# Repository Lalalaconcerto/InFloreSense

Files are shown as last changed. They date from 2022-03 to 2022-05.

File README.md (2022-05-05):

# InfloreSense

This project is to visualise and sonify moisture and temperature plant data using a leaf as the user interface: A leaf is used as a touch sensor to trigger the data to be revealed to a user. The plant’s needs were expressed visually with an 8x8 pixel matrix and auditorily with a choral voice and bass drum. We sonified the full temperature and moisture range that could be expected, allowing our users to develop an intuition for the plant’s exact conditions from listening to the audio.

## Videos

Introduction

https://youtu.be/Un4EG1IXvOg

How does it work?

https://youtu.be/Bgrby5ReTXs

## Hardware needed

- Raspberry pi
- Arduino Uno wifi 
- DHT-22 sensor(Input)
- Soil moisture sensor(Input)
- Capacitive touch sensor(Input)
- 8*8 matric LED (Output)
- Speaker(Output)

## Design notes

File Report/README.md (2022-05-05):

# InFloreSense: Visualised and Sonified Plant Data

[GitHub Repo](https://github.com/Lalalaconcerto/InFloreSense)

## Problem

Plants can be difficult to take care of. Shortly after purchase, plants frequently die due to overwatering (Vanzile 2021). Plants also often die due to underwatering after the novelty of the new plant wears off, with Art Markman of the University of Texas attributing this issue to a lack of reminders (Bregel 2019). More experienced plant-owners, such as florist Liz Vayda, recommend that the best way to become a better plant caretaker is to simply learn more about the plants and pay attention to them (Bregel 2019).

While existing plant monitors will give information about the current needs of a plant, the data they provide is either overly simplified or difficult to interpret. Additionally the data is only accessible via a visual interface. By providing data that is overly simplified, these plant monitors do not allow plant owners to develop their own intuitive sense of their plants’ needs. Providing data that is difficult to interpret can prevent the data from being acted on, potentially causing the plant owner to ignore the data completely. Lastly, the visual-only interfaces make plant monitors inaccessible to blind or hard-of-sight plant-owners.

## Motivation

Infloresense helps less experienced plant-owners keep their plants alive without stifling the learning process in which they develop an intuition for how to take care of their plants. Our device combines visual indicators of the general conditions of the plant with a sound-based mapping that expresses the conditions of the plant in more detail. By combining the visual dashboard with sonification, Infloresense will stoke curiosity in all plant-owners as they discover how the sound changes due to subtle changes in the plants’ conditions and understand what sounds indicate a healthy plant. Additionally, it makes our device accessible for blind plant-owners, who can rely solely on the sonification in understanding the plant's conditions.

## Inspiration

Having previous experience developing a standard plant monitor, our project was chiefly inspired by sonification works. Mogees is a discontinued device that would adhere to any surface, including that of trees, and by connecting to an iPhone, it would map any vibrations on that surface to a custom instrument chosen by the user. We were inspired by the way this project allowed for co-creation of music between a user and the natural environment. Ototo, a microcontroller-based device that connected to everyday objects as keys and modulators of a synthesiser, inspired us in its approach of being self-contained and not requiring a mobile phone to function. Lastly, we were inspired by the work of Mileece. Mileece attaches electrodes to plant leaves, turning voltage differences between the leaves into ambient music. We were inspired by her approach of connecting the leaves of the plant to her electronic instrument.

## Documentation of Prototyping Process

### Initial Design

We initially planned to visualise and sonify the voltage signals produced by a plant. This required significant voltage amplification, but was able to recognise water input or rustling of leaves when developed as a standalone circuit. However, the data was too noisy to capture these stimuli when other modules were attached to the Arduino. Thus, this option was not selected for this project.

### Second Design

#### User Interface

Instead of measuring intra-plant voltage, we pivoted to visualising and sonifying moisture and temperature plant data using a leaf as the user interface: we used a leaf as a touch sensor to trigger the data to be revealed to a user. The plant’s needs were expressed visually with an 8x8 pixel matrix and auditorily with a choral voice and bass drum. We sonified the full temperature and moisture range that could be expected, allowing our users to develop an intuition for the plant’s exact conditions from listening to the audio. The flow chart of the project is shown below.

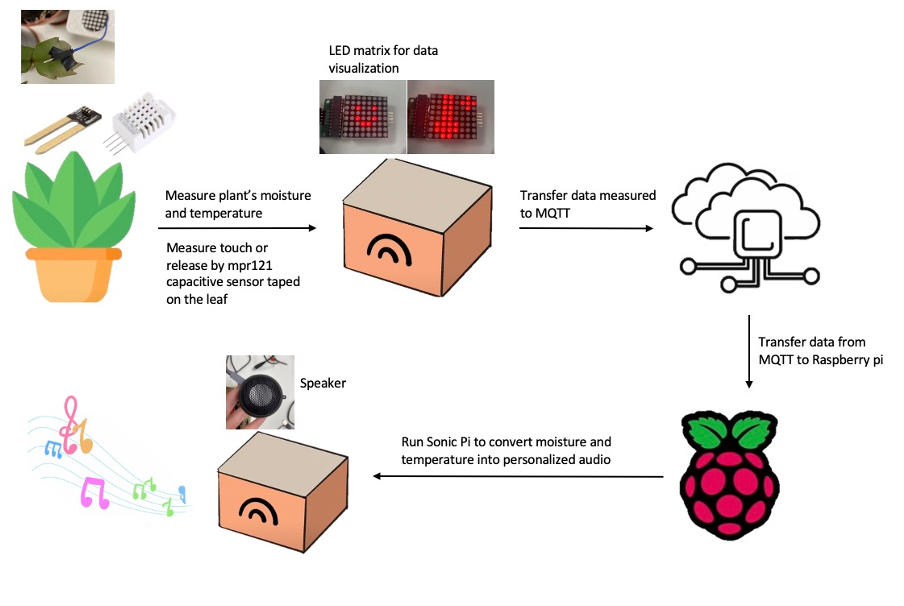
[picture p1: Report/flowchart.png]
Flow chart flow chart

  
#### Moisture sensing

Capacitive soil moisture sensor can measure the soil moisture distrectly. The main component of the sensor is the humidity sensitive capacitor and the number of absorbed water changes with the change in ambient humidity(Boudaden,et,al,2018). By measuring the capacitance value, it can be converted into a humidity value. The soil moisture value can be directly read using the digital pin of the Arduino.

#### Temperature Sensing

DHT-22 can measure ambient temperature. The principle of DHT22 measuring temperature and humidity is to measure the surrounding air through the built-in capacitive humidity sensor and thermistor(Kim,et al, 2021). After obtaining the temperature and humidity values, a digital signal is sent to the main control board from the Data pin.

#### Touch Sensing

MPR 121 capacitive touch sensor can handle up to 12 individual touch pads. Each pin can be connected to wires and be taped to leaves as a touch switch(Ada,et al,2022). We programmed it with the Arduino MPR121 library so that touch will set LED matrix and speaker on, and release will set LED matrix and speaker off.

#### Visualisation

The LED matrix consists of 64 red LEDs. Some simple images were displayed with five different icons to show different conditions of the plant. These icons are shown below; from left to right, they correspond to healthy conditions, high temperature, low temperature, overly moist soil, and overly dry soil. Every time you touch a leaf, the icon will show the current conditions until 5 seconds after your finger has been removed. If neither humidity nor temperature are in the correct range, humidity and temperature icons will be alternately displayed on the LED matrix for one second. If one metric is in a good range, then the matrix will exclusively show the icon representing the metric that needs to be changed. If both conditions are good, the smiling icon will be shown.

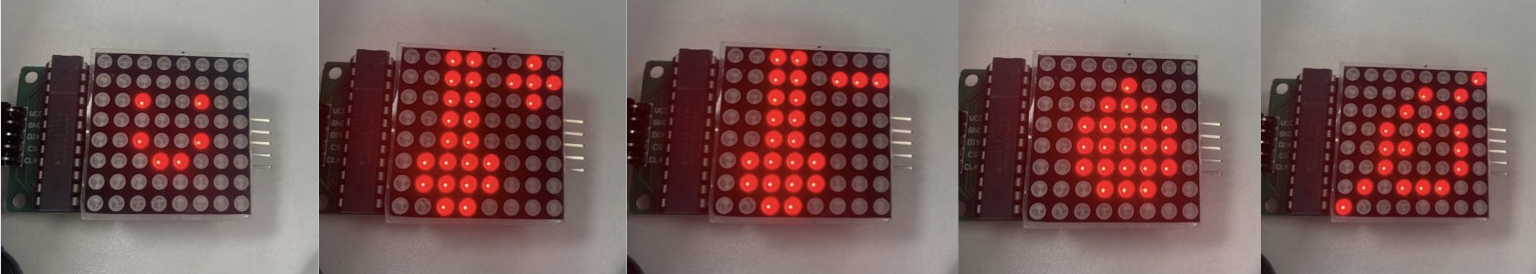
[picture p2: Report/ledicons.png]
LED icons


#### Data flow to Raspberry Pi

Moisture data, temperature data, and touch data are sent once per second to an MQTT server in a channel labelled "Infloresense". A continuously-running Python script on the Raspberry Pi monitors the MQTT data feed from the “Infloresense” channel, and stores the values in a plain text file, resetting the plain text file every second. Simultaneously, a shell script repeatedly runs runs a Sonic Pi script via a Python-based command line interface, using the plain text file as an input parameter.

#### Sonification

Sonic Pi plays two sound samples synchronously, a choral voice and a bass drum. These two samples are sped up according to the amount of moisture in the soil and temperature of the surrounding environment, respectively. Different continuous functions are used to ensure that the full range of realistic moistures and temperatures is sonified in a distinguishable and musical manner. We have specifically tied higher moisture and temperature levels to more sped up versions of the two instruments.

#### Enclosure

Before designing the enclosure, we measured the dimensions of each part individually to create a compact enclosure. However, we found that with wire connections, a larger enclosure was needed. See below for a final rendering of our enclosure.

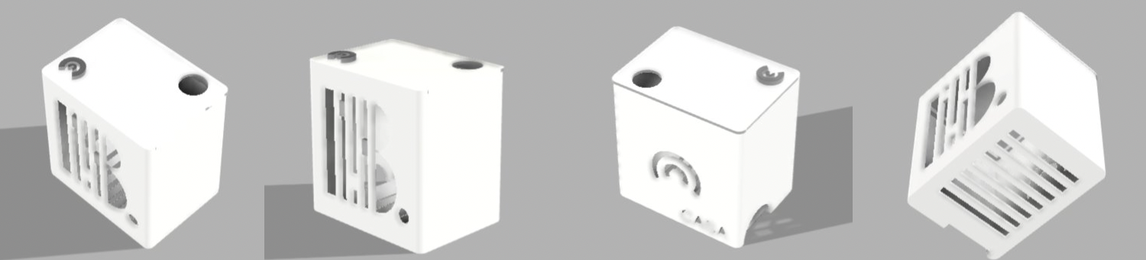
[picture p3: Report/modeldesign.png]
Model design


##### Model design

We used Fusion360 to design the enclosure. For future prototypes, we expect simulating the placement of all of the components inside the enclosure will help us to design the most spatially-efficient enclosure.

##### Wires outlet

Multiple wires need to come out of the enclosure to connect to external devices, including the charging cable for Arduino, the charging cable for a Raspberry Pi, the cable connecting the touch sensor and the cable connecting the soil moisture sensor. For this, we designed some gaps to let these wires come out of the enclosure. These gaps are designed to emulate the appearance of a sound mixer.

##### Heat dissipation

When placed in the first prototype enclosure, the Arduino and Raspberry Pi microcontrollers were found to be hot which distorted the readings of the DHT-22 sensor. To solve this problem, we added a strip-shaped gap at the bottom of the box to dissipate heat.

## Critical Reflection and Future Improvements

### All-in-one design

Currently, our device is separate from the plant, with wires exposed on the outside of the enclosure. In the future, we will design an enclosure to put all the components inside, including the plant.

### Power supply

The Raspberry Pi and Arduino board are currently powered by different external power supplies. In the future, we will place a small power strip in the enclosure to connect the two boards with an external power supply in a more consolidated manner.

### Audio hardware design

We put the speaker and other components directly into the enclosure, but this leads to poor speaker sound. If amplification could be incorporated into the outside of the enclosure, it would improve the musical quality. We are interested in testing out a thin-film loudspeaker adhered to the surface of the enclosure, as recently developed by researchers at MIT (Han, Lang, and Bulovic 2022).

### Leaf touch interface

The touch sensor is wired in a way that does not hide the wire and usually requires the user to pinch it in order to turn on InfloreSense's visualisations. To make the user interaction feel more organic, we would like to explore using an electrode pad to detect a touch to any portion of a leaf.

### More channels

Right now we only use one touch sensor. If more than one channel to connect to different leaves is used, more interesting music could be produced, based on either other parameters relating to the care of the plant, or even combining the plant's data with external sustainability or environmental data (such as the user's electricity usage, the air pollution forecast in one's neighbourhood that day, or the chance of rain).

### Accessibility

To make our device more accessible to hard-of-sight individuals, it would be worth adding an "audio-only" mode, potentially by using a wake-word to get InfloreSense to say its needs before playing the sonification until it is told to stop.

## References

Boudaden, J. _et al._ (2018) ‘Polyimide-Based Capacitive Humidity Sensor’, _Sensors_, 18(5), p. 1516. doi:10.3390/s18051516.

Bregel, S. (2019) ‘Perspective | Why I can’t take care of a plant’, _Washington Post_, 5 July. Available at: https://www.washingtonpost.com/outlook/why-i-cant-take-care-of-a-plant/2019/07/05/ee961b54-9788-11e9-8d0a-5edd7e2025b1_story.html (Accessed: 3 May 2022).

Dentaku (2014) _Ototo: Make Music from Anything_, _Kickstarter_. Available at: https://www.kickstarter.com/projects/905018498/ototo-make-music-from-anything (Accessed: 3 May 2022).

Fried, L. (2014) ‘Adafruit MPR121 12-Key Capacitive Touch Sensor Breakout Tutorial’, _Adafruit Learning System_, 25 July. Available at: https://learn.adafruit.com/adafruit-mpr121-12-key-capacitive-touch-sensor-breakout-tutorial/wiring (Accessed: 5 May 2022).

Han, J., Lang, J.H. and Bulović, V. (2022) ‘A Thin-Film Piezoelectric Speaker Based On An Active Microstructure Array’, in 2022 IEEE 35th International Conference on Micro Electro Mechanical Systems Conference (MEMS). 2022 IEEE 35th International Conference on Micro Electro Mechanical Systems Conference (MEMS), pp. 852–855. doi:10.1109/MEMS51670.2022.9699609.

Hermann, T., Hunt, A. and Neuhoff, J.G. (2011) ‘The Sonification Handbook’, p. 586.

Kim, J. _et al._ (2021) ‘Capacitive Humidity Sensor Based on Carbon Black/Polyimide Composites’, _Sensors_, 21(6), p. 1974. doi:10.3390/s21061974.

Mogees (2015) _Mogees - Play the World_. Available at: https://www.youtube.com/watch?v=G_hBhORGE6Y (Accessed: 26 April 2022).

Mogees (2016) _Mogees - Transform anything into a musical instrument._, _Kickstarter_. Available at: https://www.kickstarter.com/projects/mogeesplay/mogees (Accessed: 3 May 2022).

Motherboard (2014) _Meet the Sonic Artist Making Music with Plants: Sound Builders_. Available at: https://www.youtube.com/watch?v=wYU18eiiFt4 (Accessed: 3 May 2022).

Palmai, K. (2022) ‘How smart sensors can help us care for our houseplants’, _BBC News_, 21 February. Available at: https://www.bbc.com/news/business-60387006 (Accessed: 3 May 2022).

Vanzile, J. (2021) ‘Learn How to Not Kill Your Houseplants With Too Much Water’, _The Spruce_, 19 December. Available at: https://www.thespruce.com/tips-for-watering-houseplants-1902807 (Accessed: 3 May 2022).

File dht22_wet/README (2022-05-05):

This file is the skech for obtaining data for dht22 sensor and moisture sensor in Arduino.

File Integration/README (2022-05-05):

This is the Arduino final integration sketch.

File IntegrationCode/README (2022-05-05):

This is the integraton code for all input and output sensors in Arduino.(LED, touch sensor, dht22, and moisture sensor)

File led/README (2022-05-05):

This file is the design of the five different images according to different status of the plant with 8*8 LED matirx.

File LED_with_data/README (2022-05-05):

This file is the combination of the 8*8 LED Matrix skech and dht22 and moisture skech.

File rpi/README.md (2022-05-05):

# These files include all of the custom code needed to produce sonification of the plant's data
## Dependencies (to be installed on Raspberry Pi)
1. [Sonic Pi](https://sonic-pi.net)
2. [Sonic Pi Tool (Python)](https://github.com/emlyn/sonic-pi-tool)

## Steps to run:
1. Download all of these files to the Desktop of your Raspberry Pi
2. Open Sonic Pi
3. Run the `mqttToText.py` script in the `Thonny` Python IDE. Keep it running continuously.
4. Open a new terminal and run `watch -n 1 repeatedCheck.sh`

## Brief description of each script
- `infloresense.rb`: Sonification script, ran in Sonic Pi 
- `mqttToText.py`: updates `test.txt` with MQTT data
- `repeatedCheck.sh`: runs the Sonic Pi script every second
- `sonic-pi-tool.py`: copy of Sonic Pi Tool (mentioned above)
- `test.txt`: stores the most recent MQTT data

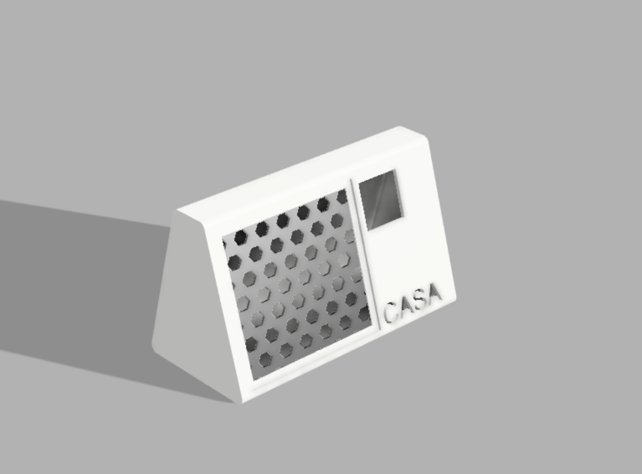
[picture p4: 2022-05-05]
Enclosure/Rendering image.png

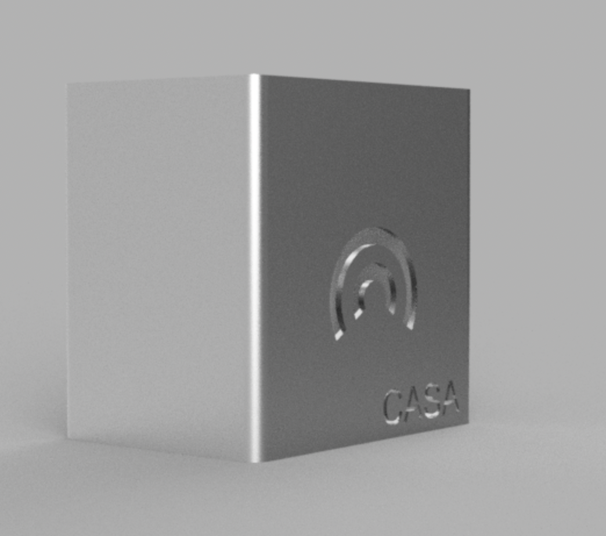
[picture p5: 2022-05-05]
Enclosure/Screenshot 2022-04-12 at 14.10.03.png

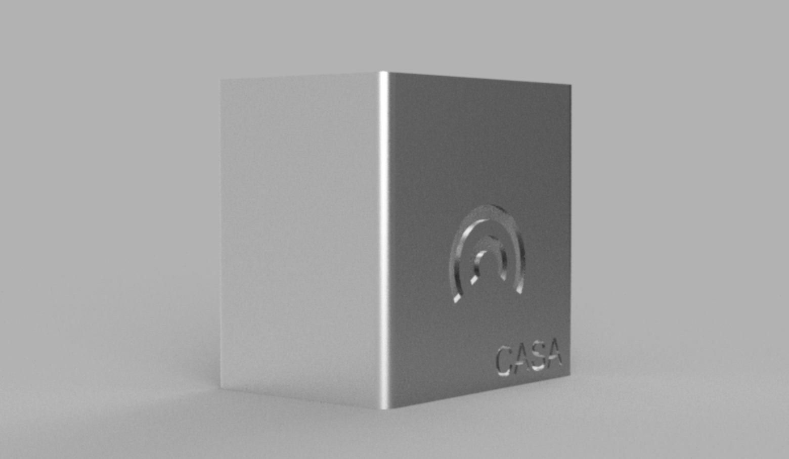
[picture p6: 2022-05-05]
Enclosure/Screenshot 2022-04-12 at 14.10.10.png

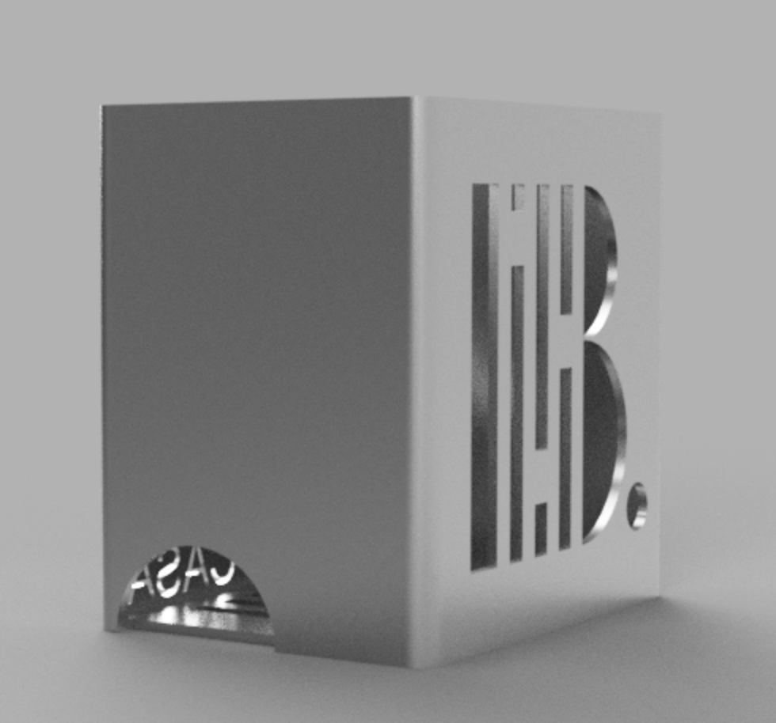
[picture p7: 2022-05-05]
Enclosure/Screenshot 2022-04-12 at 14.08.59.png

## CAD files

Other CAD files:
Enclosure/Enclosure.f3d
Enclosure/enclosure-lastEdition.f3d

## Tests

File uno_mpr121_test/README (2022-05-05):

This is the test sketch of the mpr121 sensor.

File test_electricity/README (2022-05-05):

This is for electricity test but we did not use it in the final project.

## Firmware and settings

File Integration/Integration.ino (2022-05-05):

#include <LedControl.h>
#include <Wire.h>
#include "DHT.h"
#include "Adafruit_MPR121.h"
#include <SPI.h>
#include <ezTime.h>
#include <WiFiNINA.h>
#include <PubSubClient.h>
#include "arduino_secrets.h"

#define DHTPIN 4
#define DHTTYPE DHT22
#ifndef _BV
#define _BV(bit) (1 << (bit))
#endif


DHT dht(DHTPIN, DHTTYPE);
int temp;
int hum;
int wetPin = A2;
long int wetValue = 0;
int DIN = 10;
int CS = 9;
int CLK = 8;
bool LEDON = false; //user touch
int loopCounter = 0;
int secondsSinceLastTouch = 5;
LedControl lc = LedControl(DIN, CLK, CS, 0);
// You can have up to 4 on one i2c bus but one is enough for testing!
Adafruit_MPR121 cap = Adafruit_MPR121();

bool userTouch = false;
bool goodTemperature = false;
bool goodMoisture = false;
uint16_t lasttouched = 0;
uint16_t currtouched = 0;

int status = WL_IDLE_STATUS;     // the WiFi radio's status
const char* ssid     = SECRET_SSID;
const char* password = SECRET_PASS;
const char* mqttuser = SECRET_MQTTUSER;
const char* mqttpass = SECRET_MQTTPASS;
const char* mqtt_server = "MQTT_SERVER";


WiFiClient espClient;
PubSubClient client(espClient);
long lastMsg = 0;
char msg[50];
int value = 0;
Timezone GB;

//Facial Expression
byte smile[8] =  {0x00, 0x00, 0x24, 0x00, 0x24, 0x18, 0x00, 0x00};
//moisture
byte waterdrop[8] = {0x00, 0x08, 0x1c, 0x3e, 0x3e, 0x3e, 0x1c, 0x00};
// byte waterdropkong[8] = {0x00, 0x08, 0x14, 0x22, 0x22, 0x22, 0x1c, 0x00};
byte waterdropno[8] = {0x01, 0x0a, 0x14, 0x2a, 0x32, 0x22, 0x5c, 0x80};
//temperature
byte thermometerhigh[8] = {0x32, 0x37, 0x32, 0x30, 0x30, 0x78, 0x78, 0x30};
byte thermometerlow[8] = {0x30, 0x37, 0x30, 0x30, 0x30, 0x78, 0x78, 0x30};

void setup() {
  Serial.begin(9600);
  while (!Serial) { // needed to keep leonardo/micro from starting too fast!
    delay(10);
  }
  Serial.println("Infloresense");
  delay(100);
  dht.begin();
  startWifi();
  Serial.println("Wifi started");
  syncDate();
  Serial.println("Date synced");
  client.setServer(mqtt_server, 1884);
  Serial.println("Server set");
  client.setCallback(callback);
  Serial.println("callback set");

  //mpr121
  // Default address is 0x5A, if tied to 3.3V its 0x5B
  // If tied to SDA its 0x5C and if SCL then 0x5D
  if (!cap.begin(0x5A)) {
    Serial.println("MPR121 not found, check wiring?");
    while (1);
  }
  Serial.println("MPR121 found!");

  dht.begin();
  lc.shutdown(0, false);
  lc.setIntensity(0, 5);  //Adjust the brightness maximum is 15
  lc.clearDisplay(0);

}


void printByte(byte character [])
{
  int i = 0;
  for (i = 0; i < 8; i++)
  {
    lc.setRow(0, i, character[i]);
  }
}

void getSensor() {
  temp = dht.readTemperature();
  //Caculate the wet value
  wetValue = analogRead(wetPin);
  wetValue *= 100;
  wetValue = wetValue / 1023;
}

void temled() {
  goodTemperature = false;
    if (dht.readTemperature() < 20) {
      printByte(thermometerlow);
    } else if (dht.readTemperature() > 30) {
      printByte(thermometerhigh);
    } else {
      goodTemperature = true;
      if (goodMoisture) {
        printByte(smile);
      }
    }
}

void wetled() {
  goodMoisture = false;
    if (wetValue < 30) {
      printByte(waterdropno);
    } else if (wetValue > 60) {
      printByte(waterdrop);
    } else {
      goodMoisture = true;
      if (goodTemperature) {
        printByte(smile);
      }
    }


}

void mpr121() {
  // Get the currently touched pads
  bool released = false;
 currtouched = cap.touched();
//  for (uint8_t i = 0; i < 12; i++) {
    if ((currtouched & _BV(0)) && !(lasttouched & _BV(0)))  {
      Serial.print(0); Serial.println(" touched");
      LEDON = 1;
    } else {
      LEDON = 0;
    }
    // if it *was* touched and now *isnt*, alert!
//    if (!(currtouched & _BV(i)) && (lasttouched & _BV(i)) ) {
//      Serial.print(i); Serial.println(" released");
//      released = true;
//    }
//    if (i == 11 && released) {
//      LEDON = 0;
//    }
//  }

  // reset our state
//  lasttouched = currtouched;

  // comment out this line for detailed data from the sensor!
  return;

  // debugging info, what
  Serial.print("\t\t\t\t\t\t\t\t\t\t\t\t\t 0x"); Serial.println(cap.touched(), HEX);
  Serial.print("Filt: ");
//  for (uint8_t i = 0; i < 12; i++) {
    Serial.print(cap.filteredData(0)); Serial.print("\t");
//  }
  Serial.println();
  Serial.print("Base: ");
//  for (uint8_t i = 0; i < 12; i++) {
    Serial.print(cap.baselineData(0)); Serial.print("\t");
//  }
  Serial.println();
}


void startWifi() {
  // We start by connecting to a WiFi network
  Serial.println();
  Serial.print("Connecting to ");
  Serial.println(ssid);
  WiFi.begin(ssid, password);

  // check to see if connected and wait until you are
  while (WiFi.status() != WL_CONNECTED) {
    delay(500);
    Serial.print(".");
  }
  Serial.println("");
  Serial.println("WiFi connected");
  Serial.print("IP address: ");
  Serial.println(WiFi.localIP());
}

// This function is used to make sure the arduino is connected
// to an MQTT broker before it tries to send a message and to
// keep alive subscriptions on the broker (ie listens for inTopic)


void syncDate() {
  // get real date and time
  waitForSync();
  Serial.println("UTC: " + UTC.dateTime());
  GB.setLocation("Europe/London");
  Serial.println("London time: " + GB.dateTime());

}



void sendMQTT() {
  // try to reconnect if not
  if (!client.connected()) {
    reconnect();
  }
  client.loop();
  

  snprintf (msg, 50, "%.0i", wetValue);
  Serial.print("Moisture: ");
  Serial.println(msg);
  client.publish("student/CASA0021/InfloreSense/Moisture", msg);

  snprintf (msg, 50, "%.0i", temp);
  Serial.print("Temp: ");
  Serial.println(msg);
  client.publish("student/CASA0021/InfloreSense/Temp", msg);

  snprintf (msg, 50, "%.0i", LEDON);
  Serial.print("LEDON: ");
  Serial.println(msg);
  client.publish("student/CASA0021/InfloreSense/LEDON", msg);
}
void reconnect() {
  // Loop until we're reconnected
  while (!client.connected()) {    // while not (!) connected....
    Serial.print("Attempting MQTT connection...");
    // Create a random client ID
    String clientId = "ESP8266Client-";
    clientId += String(random(0xffff), HEX);

    // Attempt to connect
    if (client.connect(clientId.c_str(), mqttuser, mqttpass)) {
      Serial.println("connected");
      // ... and subscribe to messages on broker
      client.subscribe("student/CASA0016/inTopic");
    } else {
      Serial.print("failed, rc=");
      Serial.print(client.state());
      Serial.println(" try again in 5 seconds");
      // Wait 5 seconds before retrying
      delay(5000);
    }
  }
}


// Execute code when a message is recieved from the MQTT
void callback(char* topic, byte* payload, unsigned int length) {
  Serial.print("Message arrived [");
  Serial.print(topic);
  Serial.print("] ");
  for (int i = 0; i < length; i++) {
    Serial.print((char)payload[i]);
  }
  Serial.println();
}


void loop() {
    getSensor();
    bool LEDONBEFORE = LEDON;
    if (secondsSinceLastTouch > 4) {
      Serial.println("running MPR check; secondsSinceLastTouch:");
      Serial.println(secondsSinceLastTouch);
      mpr121();
    }
    if (LEDON && !LEDONBEFORE) {
      secondsSinceLastTouch = 0;
    } else if (LEDONBEFORE) {
      secondsSinceLastTouch++;
    }
    sendMQTT();
    if (LEDON) { //alternate between temp and moisture display
      Serial.print("loop counter:");
      Serial.println(loopCounter);
      loopCounter++;
      if (loopCounter == 2) {
        loopCounter = 0;
      }
      if (loopCounter == 0) {
        temled();
      } else {
        wetled();
      }
    } else {
      lc.clearDisplay(0);
    }

    Serial.println(GB.dateTime("H:i:s")); // UTC.dateTime("l, d-M-y H:i:s.v T")
    delay(1000);

}

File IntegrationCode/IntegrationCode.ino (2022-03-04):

#include <LedControl.h>
#include <Wire.h> 
#include "DHT.h"

#define DHTPIN 4
#define DHTTYPE DHT22
DHT dht(DHTPIN, DHTTYPE);
int temp;
int hum;
int wetPin = A2;     
long int wetValue = 0; 
int DIN = 10;
int CS = 9;
int CLK = 8;
LedControl lc = LedControl(DIN, CLK, CS, 0);

uint8_t leafPin = 0;
int voltage_val;
int counter;
int baseCounter = 1;
float baseVoltageAverage;
int baseVoltageMax;
bool userTouch = false;

  //Facial Expression
  byte smile[8] =  {0x00, 0x00, 0x24, 0x00, 0x24, 0x18, 0x00, 0x00};
  //moisture
  byte waterdrop[8] = {0x00, 0x08, 0x1c, 0x3e, 0x3e, 0x3e, 0x1c, 0x00};
  byte waterdropno[8] = {0x01, 0x0a, 0x14, 0x2a, 0x32, 0x22, 0x5c, 0x80};
  //temperature
  byte thermometerhigh[8] = {0x32, 0x37, 0x32, 0x30, 0x30, 0x78, 0x78, 0x30};
  byte thermometerlow[8] = {0x30, 0x37, 0x30, 0x30, 0x30, 0x78, 0x78, 0x30};

  // optimal-range indicator values for determining smile
  bool goodTemperature = false;
  bool goodMoisture = false;

void assessBaseVoltageAverageMax() {
  int baseVoltageSum = 0; // The total voltage incrementally added in order to find an average voltage value
  int baseVoltageMax = 0;
  for (int i = 0; i < 20; i++) {
    int baseVoltageReading = analogRead(leafPin);
    baseVoltageSum += baseVoltageReading;
    if (baseVoltageReading > baseVoltageMax) {
      baseVoltageMax = baseVoltageReading;
    }
    delay(100);
  }
  baseVoltageAverage = baseVoltageSum / 20.0;
}

void setup() {
  Serial.begin(9600);  
  dht.begin();
  lc.shutdown(0, false);
  lc.setIntensity(0, 5);  //Adjust the brightness maximum is 15
  lc.clearDisplay(0);
  delay(1000);
  assessBaseVoltageAverageMax();
}

// Visualises a byte array in an 8x8 bit graphic
void printByte(byte character []) {
  int i = 0;
  for (i = 0; i < 8; i++)
  {
    lc.setRow(0, i, character[i]);
  }
}

void getSensor(){
  temp = dht.readTemperature();
  //Caculate the wet value
  wetValue = analogRead(wetPin);
  wetValue *= 100;
  wetValue = wetValue/1023;
}

// Converts the temperature reading into an LED symbol
void templed(){
   goodTemperature = false;
   if (dht.readTemperature()< 20){
     printByte(thermometerlow);
     delay(1000);
  } else if(dht.readTemperature() > 30){
     printByte(thermometerhigh);
     delay(1000);
  } else { // If the temperature and the moisture are both in good ranges, will return a smile 
     goodTemperature = true;
     if (goodMoisture) {
       printByte(smile);
       delay(1000);
     }
  }
}
  
void wetled(){
   goodMoisture = false;
   if (wetValue < 30) {
     printByte(waterdropno);
     delay(1000);
  } else if (wetValue > 60) {
     printByte(waterdrop);
     delay(1000);
  } else {
     goodMoisture = true;
     if (goodTemperature) {
       printByte(smile);
       delay(1000);
     }
  }
}

void electricity(){
  voltage_val = analogRead(leafPin);
  Serial.println(voltage_val);
  float cutoffValue = (baseVoltageMax > 1.5 * baseVoltageAverage) ? baseVoltageMax * 1.1 : 1.5 * baseVoltageAverage;
  if (voltage_val > cutoffValue) { // 400 is a cutoff value we found to be consistent with massaging a plant leaf
    userTouch = true;
  }
  if (baseVoltageMax)
  delay(100);  
}

void loop() {
  getSensor();
  templed();
  wetled();
  electricity();
  delay(100);
}

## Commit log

2022-02-04 LED VISUALISATION
2022-02-10 Update LED with data.ino
2022-02-21 Capturing user touch, first version
    Touch voltage value (experimental)
2022-03-04 Adding comments to plant monitor + LED one-item codes
2022-03-04 Adding comments + Debugging LED_with_data
2022-03-09 [Test]Connect mpr121 to Arduino uno Board
2022-05-04 adding raspberry pi folders
